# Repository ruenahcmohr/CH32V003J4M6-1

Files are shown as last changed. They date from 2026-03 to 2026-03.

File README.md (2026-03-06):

# CH32V003 breakout

The intent of this board is something that can have wires soldered to the pads and be glued into simple devices.
It breaks out all the ch32 pins, has a decoupling cap, a power LED and a programming header.

I soldered the test unit as a SIP module.

As normal for me, I have removed most of the silk screen. 
Be careful of where pin 1 of the ch32 goes. The edge pins are numbered 1:1 with the ch32.

The LED is reverse mounted to shine thru the hole. I wanted to try this on a manufactured pcb, 
but the hole is small and it didn't work out as awesome as it does on protoboard.

I used a 3.3k resistor for the LED. I reccomend 2.2k, but with bright LEDs 10k is probably fine.

The capacitor is decoupling, so any 0805 between 0.01uF and 3F should do.

I included the gerbers, but jokes on you, kicad didn't backport their versions far enough and I'm using 
5.1.9 haha!

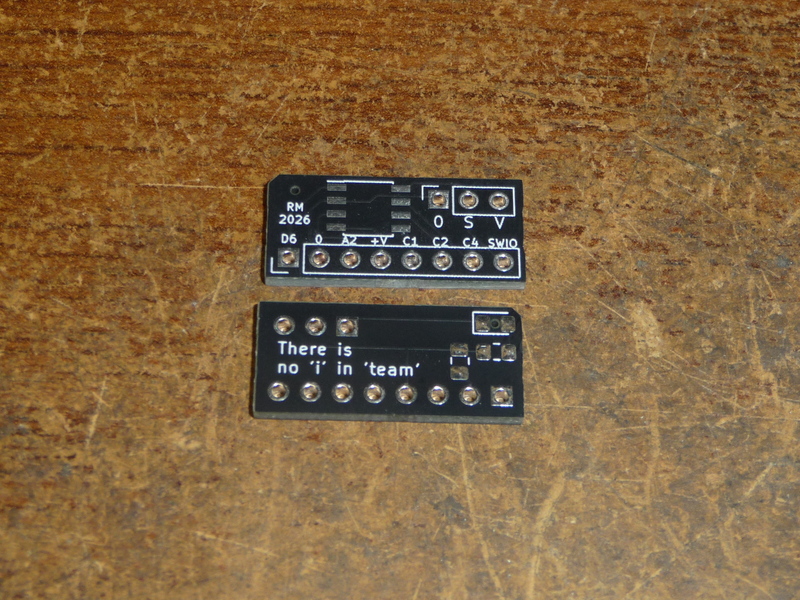
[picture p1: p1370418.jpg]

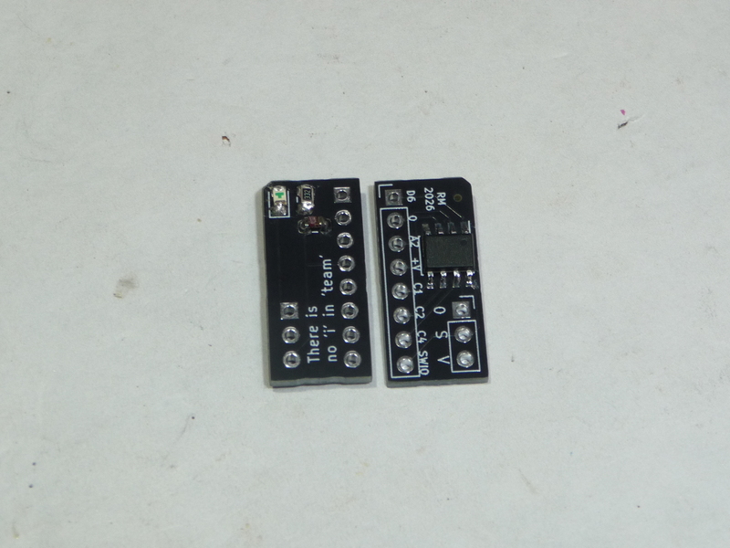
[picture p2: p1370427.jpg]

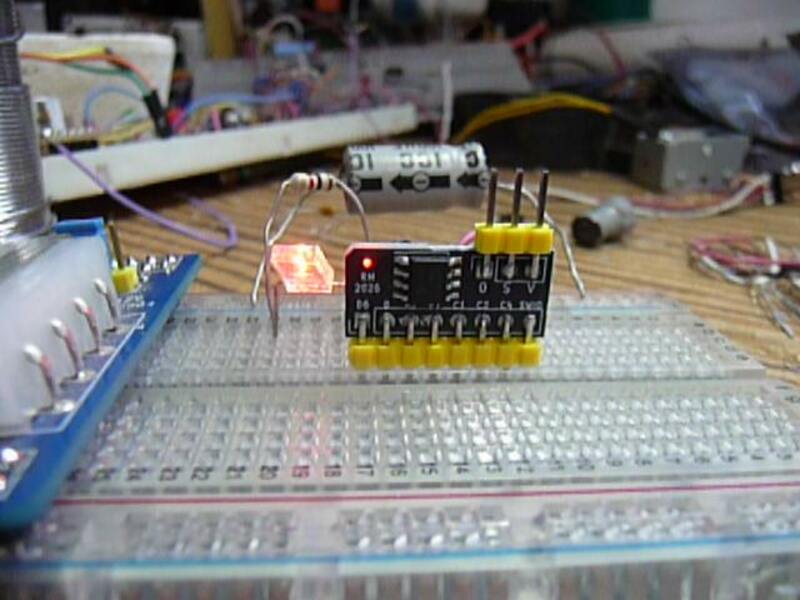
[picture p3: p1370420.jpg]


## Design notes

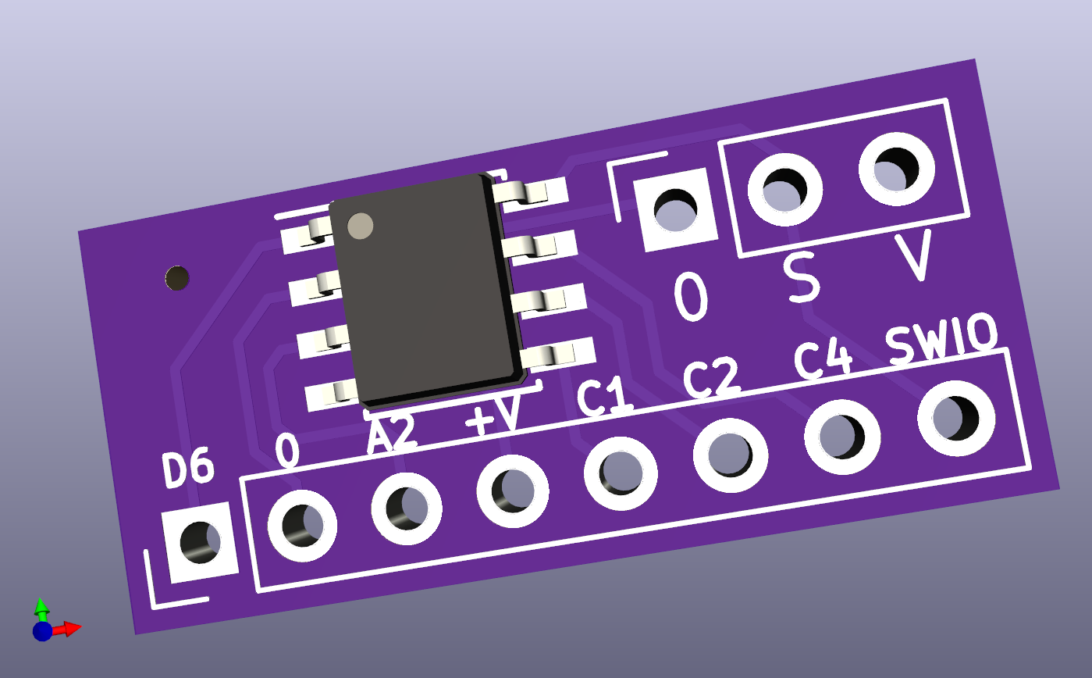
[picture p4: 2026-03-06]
ch32_8_top.png

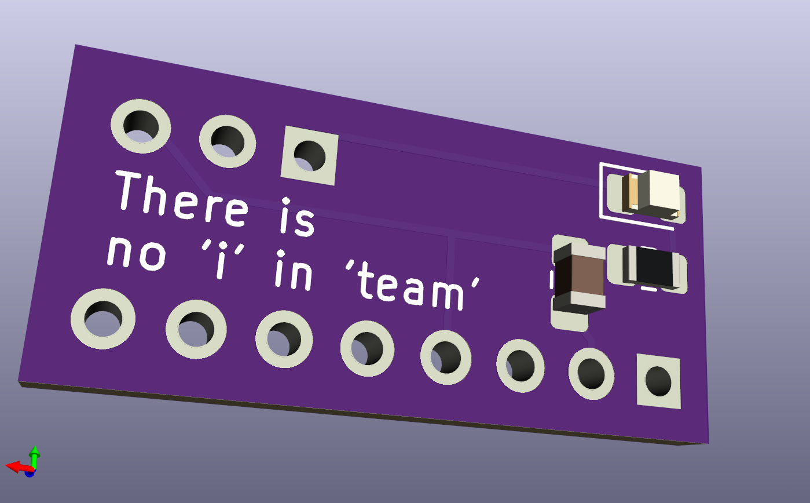
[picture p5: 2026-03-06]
ch32_8_bot.png

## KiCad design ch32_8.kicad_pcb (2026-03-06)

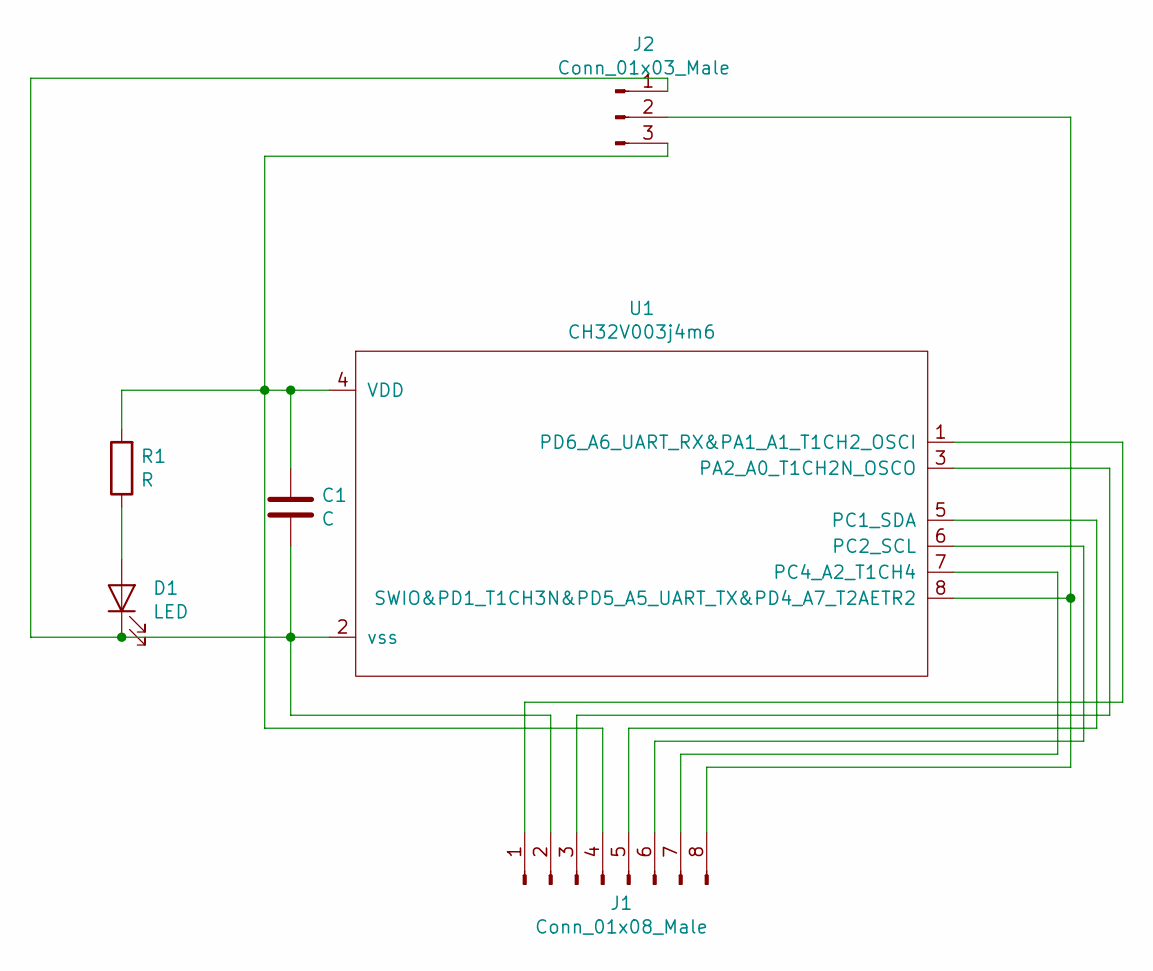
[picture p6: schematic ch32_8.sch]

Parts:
C1: C; C_0805_2012Metric_Pad1.15x1.40mm_HandSolder
D1: LED; LED_0805_2012Metric_Pad1.15x1.40mm_HandSolder
J1: Conn_01x08_Male; PinHeader_1x08_P2.54mm_Vertical
J2: Conn_01x03_Male; PinSocket_1x03_P2.54mm_Vertical
R1: R; R_0805_2012Metric_Pad1.15x1.40mm_HandSolder
U1: CH32V003j4m6; SOIC-8_3.9x4.9mm_P1.27mm

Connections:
unnamed: C1.1, J1.4, J2.3, R1.2, U1.4 (VDD)
unnamed: C1.2, D1.1 (K), J1.2, J2.1, U1.2 (vss)
unnamed: D1.2 (A), R1.1
unnamed: J1.1, U1.1 (PD6_A6_UART_RX&PA1_A1_T1CH2_OSCI)
unnamed: J1.3, U1.3 (PA2_A0_T1CH2N_OSCO)
unnamed: J1.5, U1.5 (PC1_SDA)
unnamed: J1.6, U1.6 (PC2_SCL)
unnamed: J1.7, U1.7 (PC4_A2_T1CH4)
unnamed: J1.8, J2.2, U1.8 (SWIO&PD1_T1CH3N&PD5_A5_UART_TX&PD4_A7_T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)

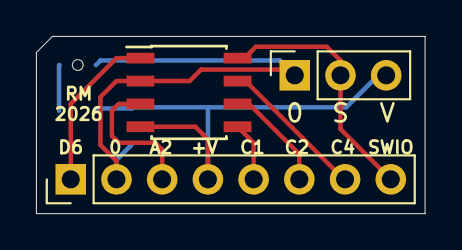
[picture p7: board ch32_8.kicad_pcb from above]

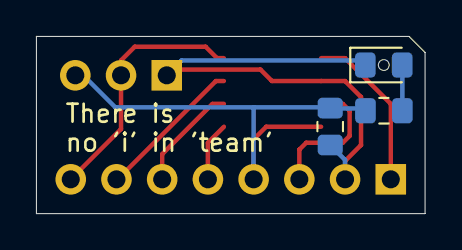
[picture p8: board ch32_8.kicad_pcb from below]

Board: 2 copper layers, 21.6 x 9.8 mm, 6 parts (3 on the bottom side), 9 nets.
